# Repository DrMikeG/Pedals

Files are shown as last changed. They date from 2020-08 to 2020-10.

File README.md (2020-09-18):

# Pedals

conversation:

- General
- Bach and piano

- Electric piano (Dad was a vicar - church organ)
- Foot pedals and midi

- Organ pedals.

Fotdella

12 pedals.

On/off
Force / impulse to determine volume (optional)

Plugs into keyboard.

Untransposed note?

- Recording
- Bass

- Roland VR-09B Combo

Pedalboard: PK-9

AC adaptor Via PK cable

MP-113
Width: 54 cm / 21,3"
Depth: 42 cm / 16,5"
Height: 14 cm / 5,5"

https://www.thomann.de/gb/doepfer_mbp25_electronic_with_1_pedal.htm

dimension of one bass pedal: about 530 mm (length) x 380 mm (depth) x 95 mm (height)

480

446 + 1 space

10 white keys
7 black keys
2 gaps

19 key
18 gaps

# Project Update 18th September #

I'm making this because I have a friend who is interested in trying to play it - but not interested enough to pay £500 to try playing it.
And I've really been enjoying this project.

I don't usually do work in progress videos, but this project has been going over a month now, and I felt I had learned enough to warrant a quick recap.

I'm attempting to build - from scratch, a set of 13 midi organ-style pedals.

It will be mostly 3d printed, and I'm using magnets and hall effects sensors.

I'm using the hugely powerful Teensie 4.0 as the midi controller, and that has 14 analog inputs, which greatly simplifies the build.

Power requirements.
I had a KY-024 linear hall effect breakout board in my parts bin so I started designing around that, rather than the raw sensor.
It has useful features, such as a power LED and an onboard comparator so it can return either an analog or digital reading, with a trim pot to adjust the digital sensitivity.
Now I plan on going analog, because I plan on measuring key velocity, but being able to use the build in LEDs for power and signal is really appealing for debugging the build.

The power draw of the board was a concern, because the Teensie is limited to 250ma (which itself is impressive for a microcontroller regulator) - but had literally no idea what the 13 KY-024 dev boards might draw.
Measuring it, I came out with 6.5mA - which sounded much too low for two bright (althought small) LED - but having sought some advice from the PJRC forum, it seems that is resonable, and I can power all 13 boards direct from the teensie.

I aiming to keep the BOM low, so I'm trying to use commodity parts. When you start to multply everything by even just 13 - things start to get expensive.

Designing the keys.

My key design is a simple pivot. I considered levers and gears, but discussing that with the my friend who has experience with organ pedals, they don't tend to have much simpler mechanics than piano keys.

Springs are expensive - and to start with I wanted large compass springs like many organ pedals used. I made a rig to bend coat hanger wire into springs.
That worked surprisingly well, although with a double coil the springs were much two powerful, and with only a single coil they tended to bend plastically not elastically.

So I trawled ebay for cheap springs and found 20 tension springs for £6. So I splashed out.
It turns out that 15mm springs are very small, but strong enough for my purpose.
But it required a major key re-design to make a level long enough for the spring travel.

Making a full size cardboard mock of the keyboard taught me lots of things.

Firsty, the keys are tightly packed. I mean, really tight. The width of keyboard I wanted was just wide enough for the dev boards.
Which is helpful because it means I can design sharp and natural keys with the same mechanism, not having to design neighbouring keys with an offset.

It turns out that although the distance moved

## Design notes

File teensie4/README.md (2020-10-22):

I've just started looking at the teensie 4.0

It has 14 analog pins, but 4 of them are on the rear of the board, not accessed via holes.

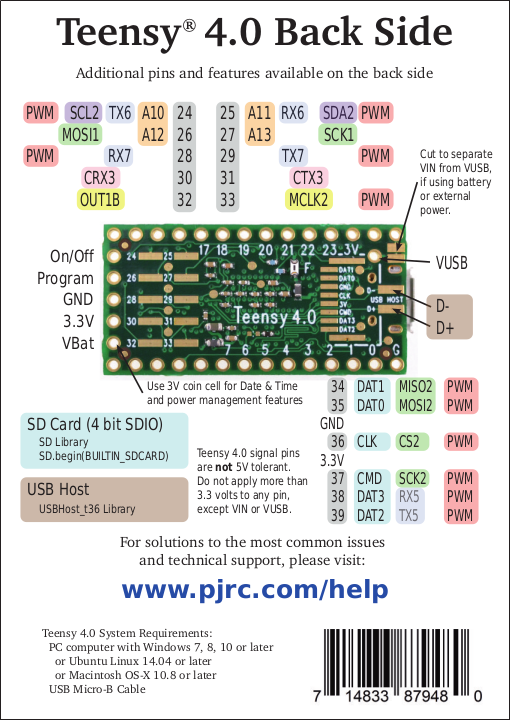
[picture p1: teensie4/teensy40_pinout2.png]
Teensy Rear Side


I'm going to want access to pins 24-27.

There is a discussion of how to do this here:
https://forum.pjrc.com/threads/59817-Teensy-4-0-accesing-24-to-33-pines?highlight=pogo

I have ordered https://www.sparkfun.com/products/13925 this pin header set via ebay.

In the mean time I want to research two components:

KY-024 Hall Effect breakout.

https://arduinomodules.info/ky-024-linear-magnetic-hall-module/

Wired up to the nano using 3v power. Using arduino serial plot. The flat side of the package seems to be where you want to position the magnet for best reading/range.

These seem really easy, so I've ordered a stack of these. Need to think about a 3d holder.

KY-016 RGB Full Colour LED.

https://arduinomodules.info/ky-016-rgb-full-color-led-module/

Teensie Midi

https://www.pjrc.com/teensy/td_libs_MIDI.html

MIDI uses the hardware serial ports to communicate with standard MIDI devices at 31250 baud.
This page documents ordinary serial MIDI which uses round 5-pin DIN connectors.
You can use Serial.print() to observe what your program is doing, while using MIDI, or USB MIDI.

MIDI input requires an optically isolated input. Output requires only 2 resistors. This schematic is recommended for Teensy 4.x & 3.x & LC:

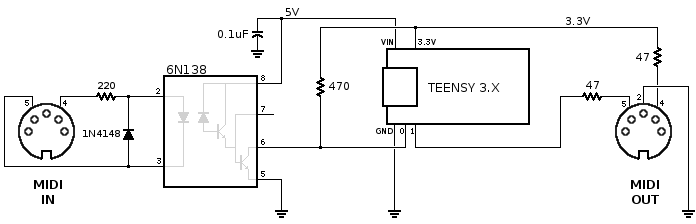
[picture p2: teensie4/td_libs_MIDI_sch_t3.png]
Midi Circuit


When connecting the signals on the 5 pin DIN connectors, be sure to connect to the correct pins.

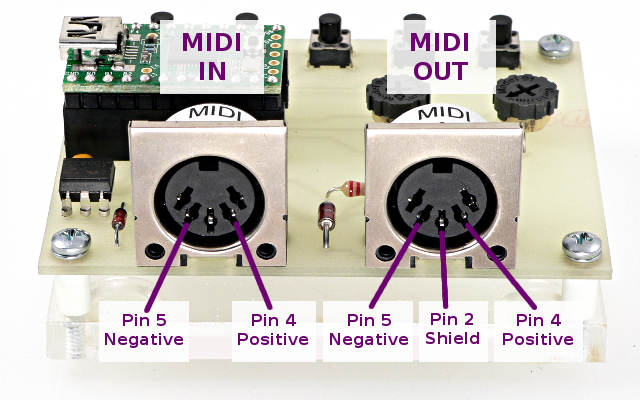
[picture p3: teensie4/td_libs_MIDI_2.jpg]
Midi Wiring


So, let's see if I understand this:

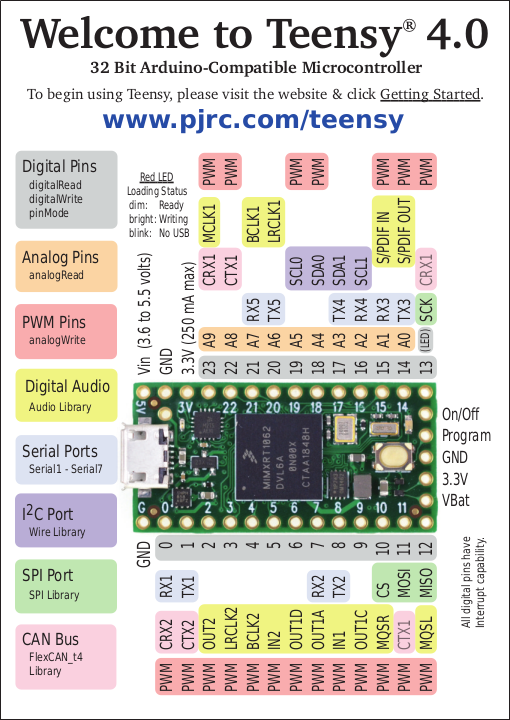
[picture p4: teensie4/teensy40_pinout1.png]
Teensy Front Side


47 ohm resistors

GND wire to pin 2 
Pin 1 is TX1 via 50ohm resistor to send - pin 5 on DIN
3.3V wire via 50ohm resistor to pin 4 (positive)

I've arranged the 3 pin headers in an L-shape
[1][2]
   [3]

[1] = rx/1 din pin 5 orange
[2] = 3.3v din pin 4 green
[3] = gnd  din pin 2 yellow

[orange][green ]
        [yellow]

https://forum.pjrc.com/threads/61941-Exponential-Moving-Average-How-does-it-work

6.5ma = 85ma

Most 3mm LEDs will be rated 20mA maximum, so 30mA is possibly bad for them.  Modern hyperbright LEDs need a lot less than 20mA to be
bright enough for indoor use...  Perhaps your 3mm LEDs are only superbright or ultrabright? (Actually I can't remember which of
these ghastly marketing terms is supposed to be the brightest!).

As LEDs evolved from the first primitive red GaAs LEDs the brightness was improved a 1000 times or more, so there are lots of different
brightnesses available depending on the process used.  The datasheet will normally say what the luminous intensity, beam angle and
luminous flux are for a given forward current.  Just beam angle can have massive effect on luminous intensity.

These days properly bright LEDs use heterojunction/quantum well design similar to semiconductor lasers, and are getting pretty close to
100% quantum efficiency.

1--5mA is normally plenty for a modern indicator LED.  The smaller the LED the less current you need for it to hurt your eyes!

## 14th Sept 2020 ##

I've printed KeyMechRig05.stl and KeyMech02.par
Changes required.
Spring needs to mount parallel betwee rear arm and rear fixing. Needs more stretch at rest 2-3mm
Could change mounting position to print without support if it only pulled on one side of the rear post.

Board mount for sensor is higher than before. Lower by ~2 mm
Board still tends to twist. Add bar at rear and tabs at front,

Cannot tap screws into central screw holes. Not enough clearance.
Front and rear screw holes are a bit close to the front surfaces.

How to wire FC16P

## Start again ##

I wired up all the analog pins incorrectly - I mirrored the pin placement and wired them up to the digital pins on the wrong edge of the teensy.

Doh.

Thankfull I was able to remove the teensie from the protoboard and start again.

My on/off switches arrived today. They have an internal resistor for the LED.

They draw about 1ma at 3.3V.
If I connect black to gnd and brown to 3.3 then the LED lights up when the teensy is on.
If I wire yellow to gnd and orange to on/off - then a long hold turns off the teensie (this turns off 3.3V but not 5V) so the LED goes off. A short press turns it back on.
Can I reduce the number of wires to 3? I've asked the forum because I am not sure.

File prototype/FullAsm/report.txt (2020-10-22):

Report Name: C:\Users\gibbens\Documents\Arduino\Pedals\prototype\FullAsm\report.txt
Report Time: 24/09/2020 18:41:09
Report Options:
    Part Names

Select Set #1:
    MockKeyNatural.par:2

Select Set #2:
    LeftRailHolder.par:1

Interferences:
    1 of 1
    MockKeyNatural.par:2
    LeftRailHolder.par:1

    1 Interferences Detected

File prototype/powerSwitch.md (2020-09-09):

This strain relief bar has 2.75mm holes (which are threaded by M2.5 screws.)
The holes are 40.8mm apart to match short side of perf board
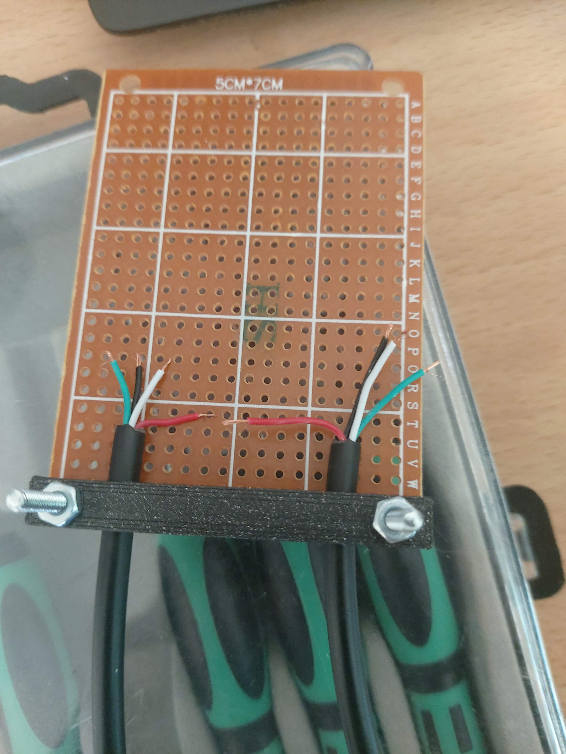
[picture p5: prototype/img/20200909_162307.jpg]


What about the micro usb wire colours?

Red     Ground

Black   D+

White   VCC

Green   D-

Not trusting the breakout board entirely,
I just put a battery pack on the socket end and did indeed get +5V from White to Red!

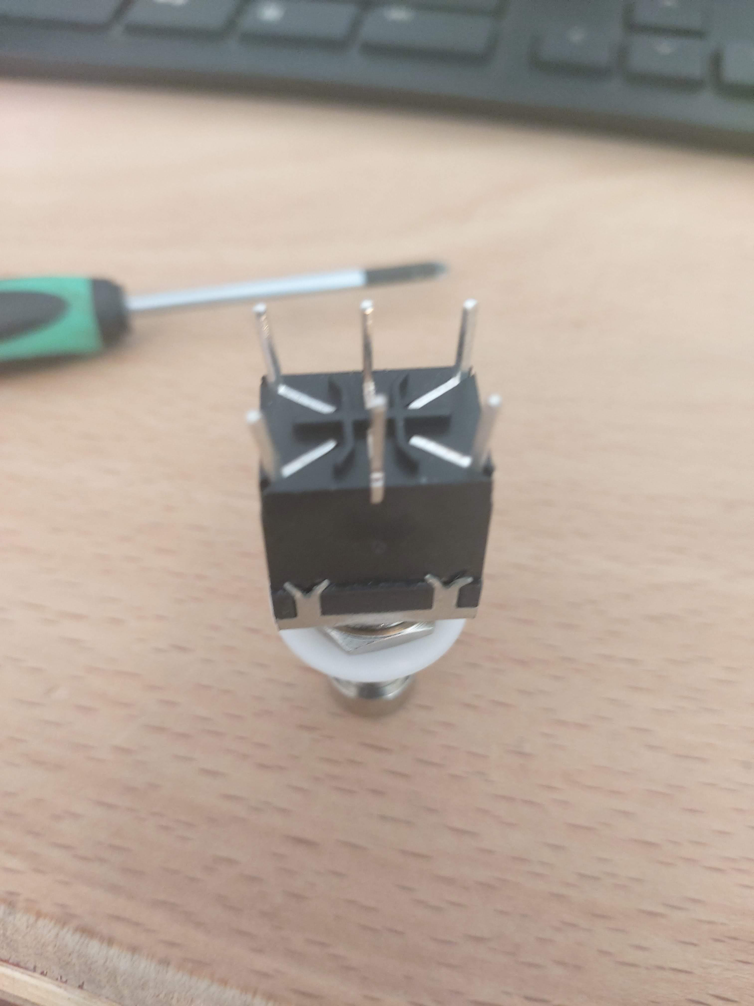
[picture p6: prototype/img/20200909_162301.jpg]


The switch is two 3 terminal switches.
Along each long side are three legs, A,B,C
B is the common terminal, switching between AB and BC.

I plan to put ground on one side and 5V on the other.

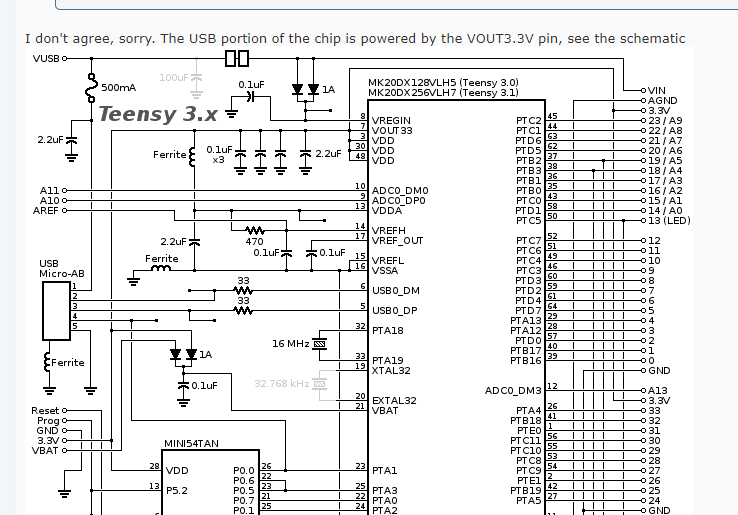
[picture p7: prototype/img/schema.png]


My question was can I just run 5v into the teensie via the microUSB connector and tap off the Vin pin to power all my 13 hall effects boards (26 LEDS!)

Looks like the answer is no, as I'm guessing the wavy line between the micro usb pins and VUSBin is some sort of fuse.

So, I will need to tap off the switch board another 5V source.

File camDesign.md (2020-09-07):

https://nolte-nc-kurventechnik.homepage.t-online.de/en/cam-design.html

Cam
Follower

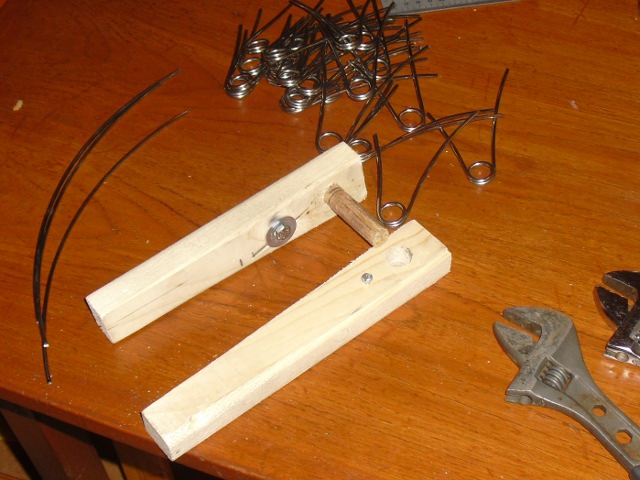
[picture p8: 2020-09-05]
prototype/img/springtools.jpg

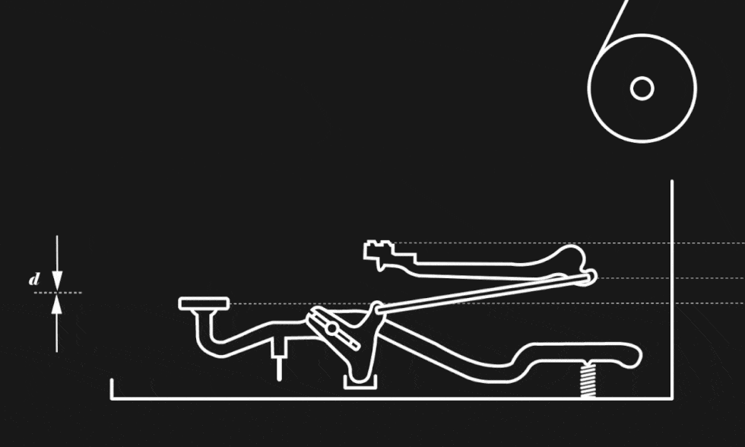
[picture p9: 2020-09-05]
prototype/img/gallery-1452611667-the-travel-typewriter04.gif

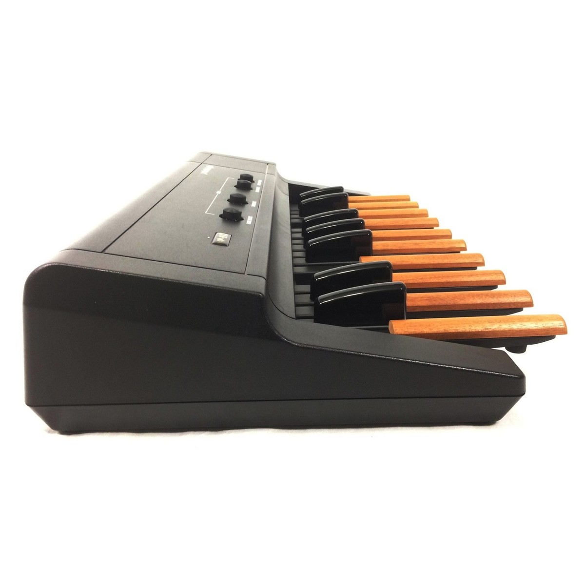
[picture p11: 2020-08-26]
readme_img/stud_03.jpg

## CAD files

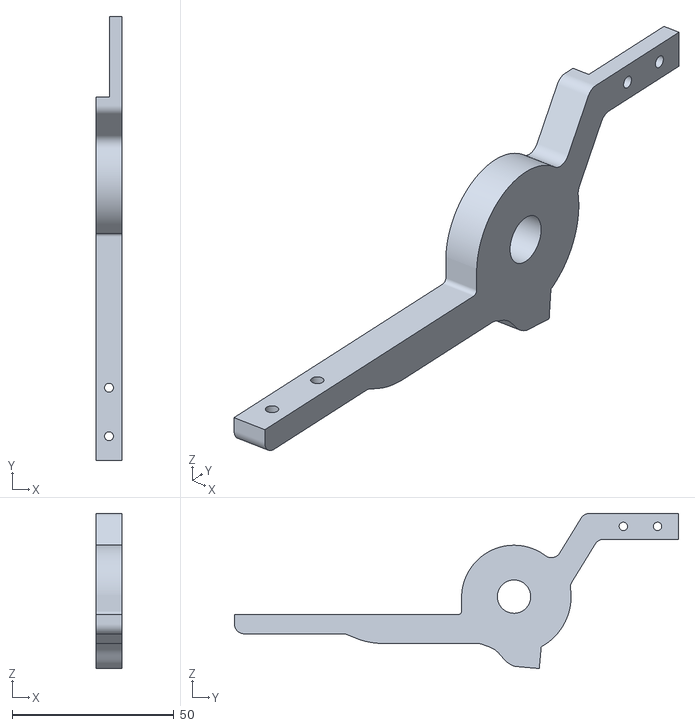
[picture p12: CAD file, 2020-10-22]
prototype/KeyMech05Main.stl
8.00 x 137.3 x 48.0

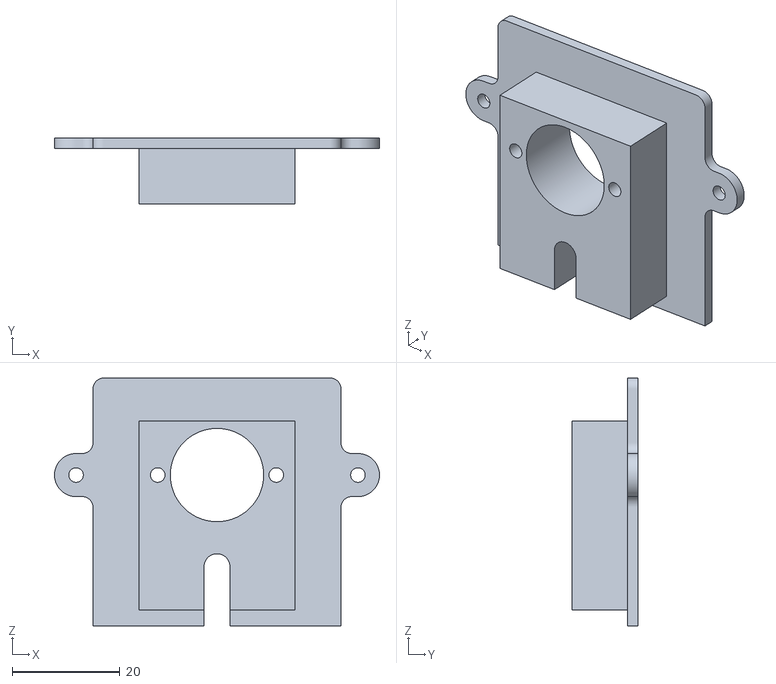
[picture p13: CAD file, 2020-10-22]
prototype/DinSupportRearPlateMain.stl
60.3 x 12.3 x 46.0

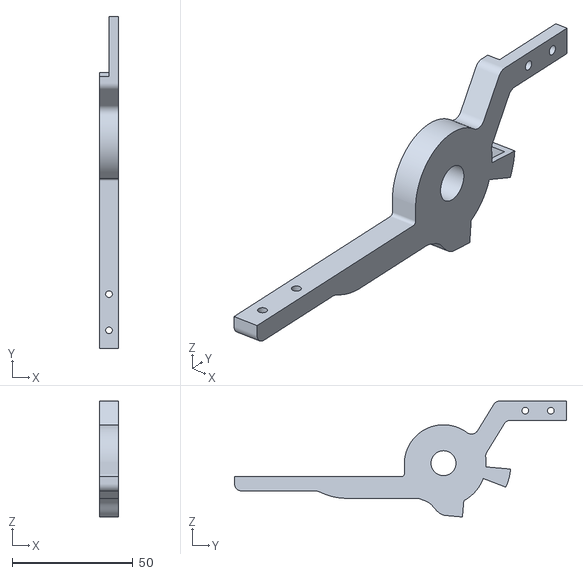
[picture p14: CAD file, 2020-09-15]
prototype/KeyMech04Main_NoBearing.stl
8.00 x 137.3 x 48.0

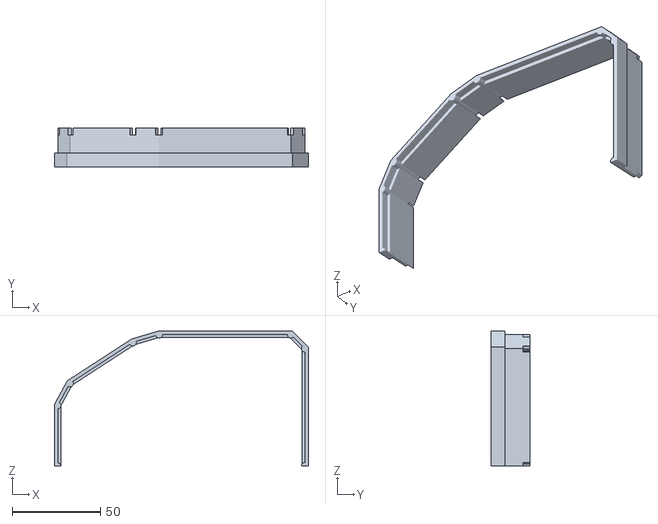
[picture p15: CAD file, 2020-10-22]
prototype/clam/clam01.stl
144.0 x 22.0 x 76.5

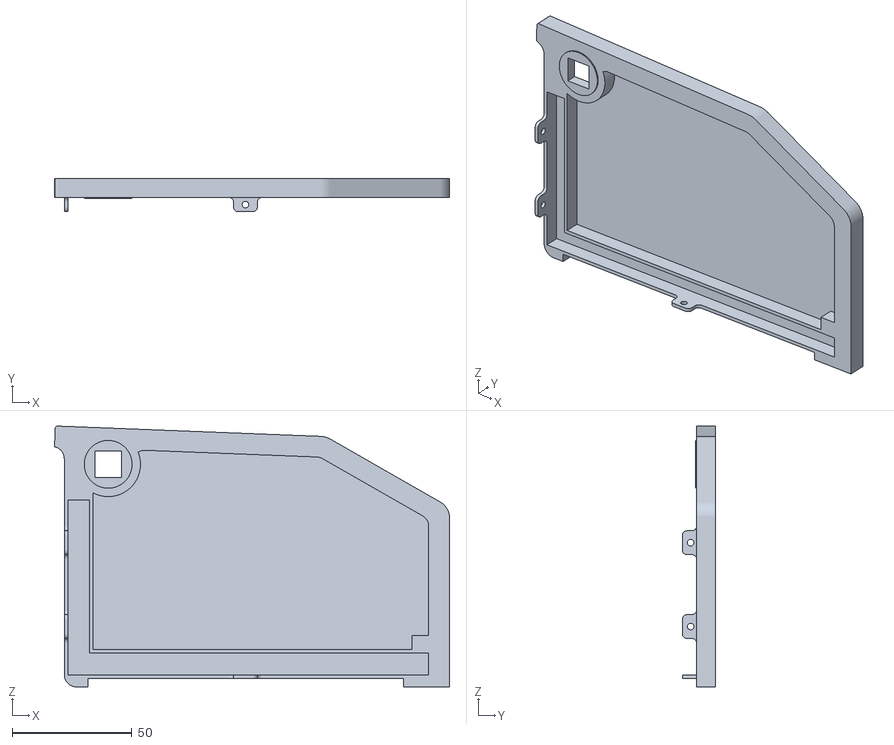
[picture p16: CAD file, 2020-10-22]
prototype/HingeEndDesign02Mirror.stl
165.3 x 14.0 x 109.1

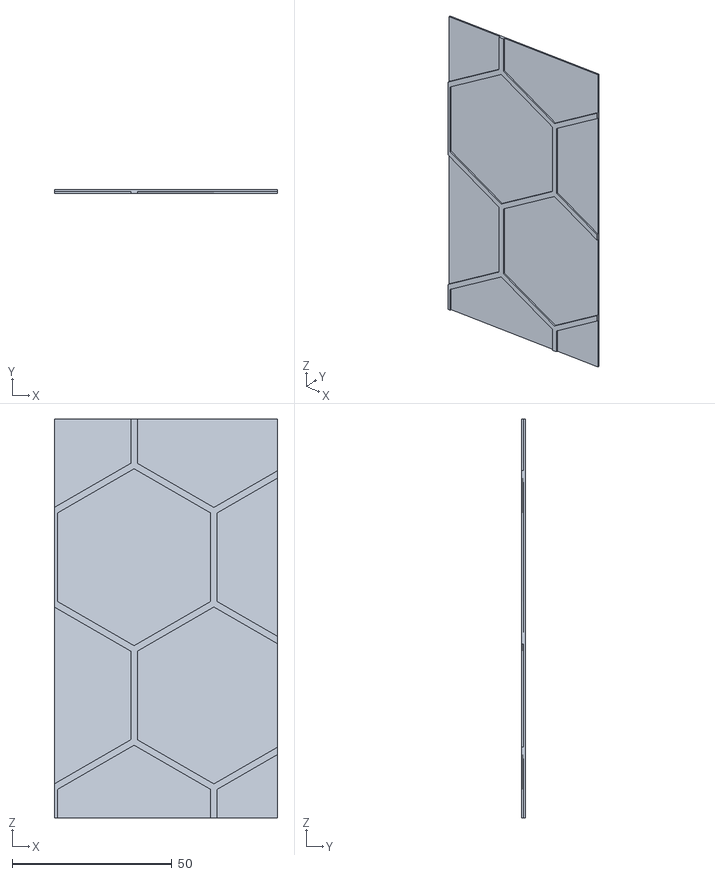
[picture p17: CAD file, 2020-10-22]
prototype/clam/clam02.stl
70.0 x 1.20 x 125.0

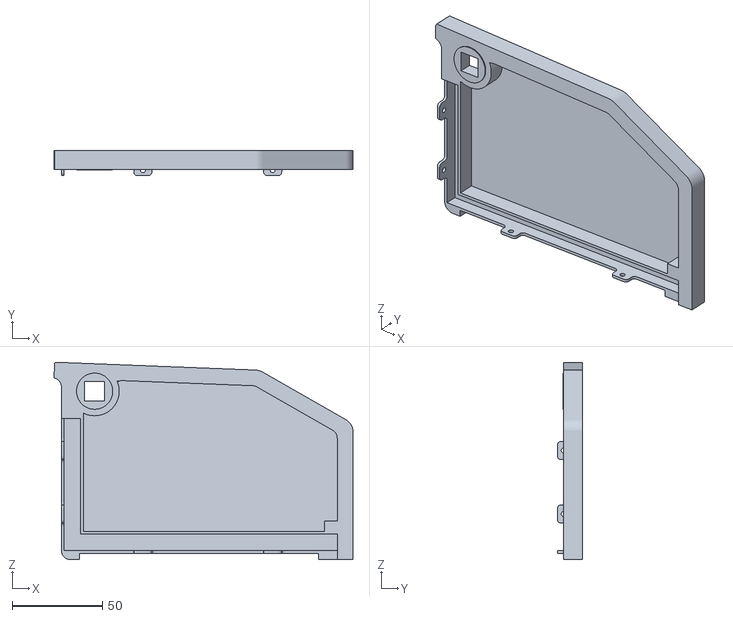
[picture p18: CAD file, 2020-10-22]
prototype/EndDesign02Mirror.stl
165.3 x 14.0 x 109.1

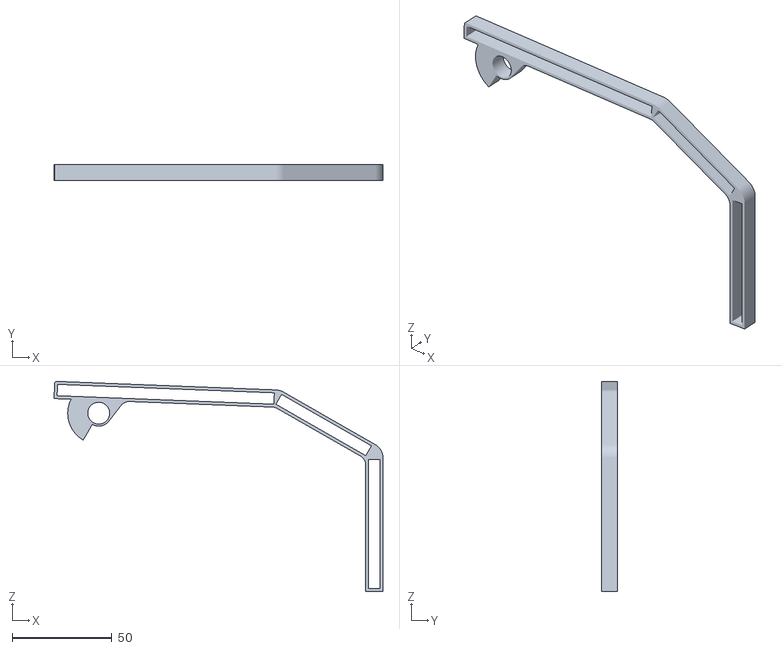
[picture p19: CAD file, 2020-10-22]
prototype/HingeEndDesign01.stl
165.3 x 8.00 x 105.6

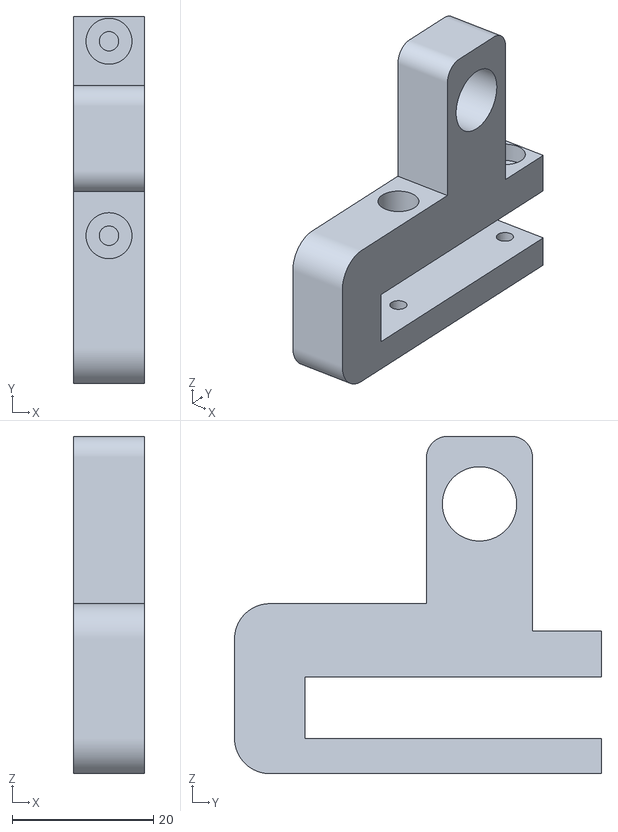
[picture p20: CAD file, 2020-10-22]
prototype/MidRailHolder.stl
10.0 x 51.9 x 47.7

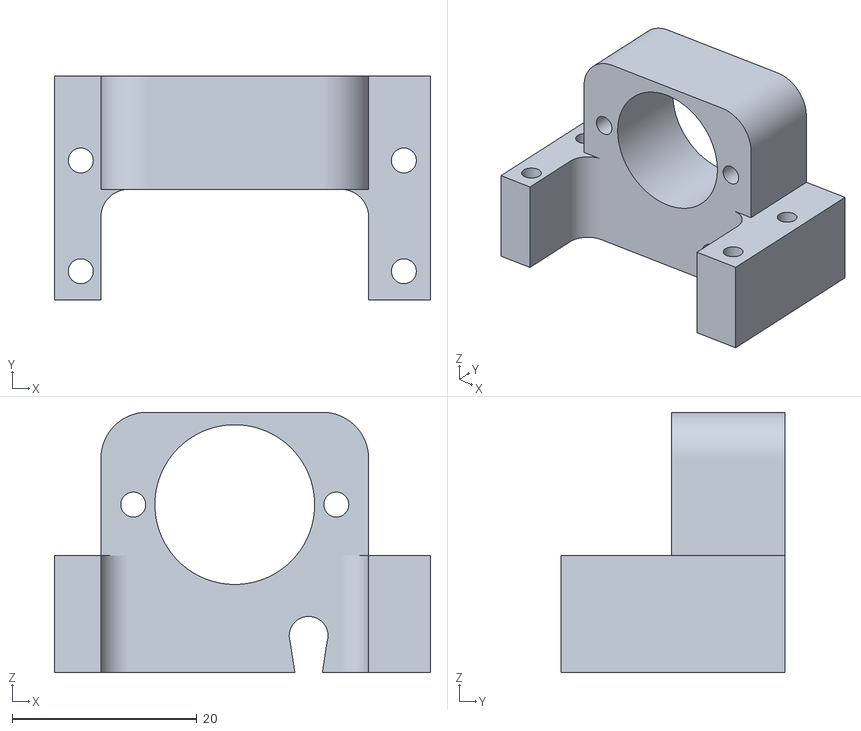
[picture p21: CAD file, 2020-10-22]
prototype/DinSupportAndOnOff.stl
40.7 x 24.3 x 28.2

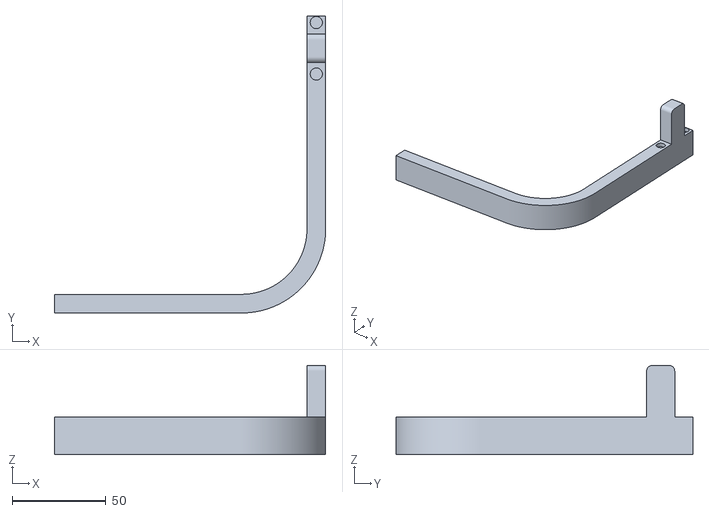
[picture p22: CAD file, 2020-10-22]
prototype/RightRailHolder.stl
145.0 x 158.7 x 47.7

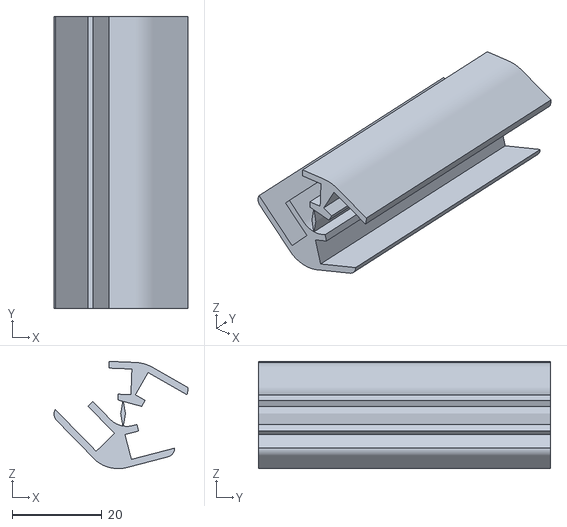
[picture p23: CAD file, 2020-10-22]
prototype/MushroomRailTop01.stl
29.8 x 65.0 x 23.8

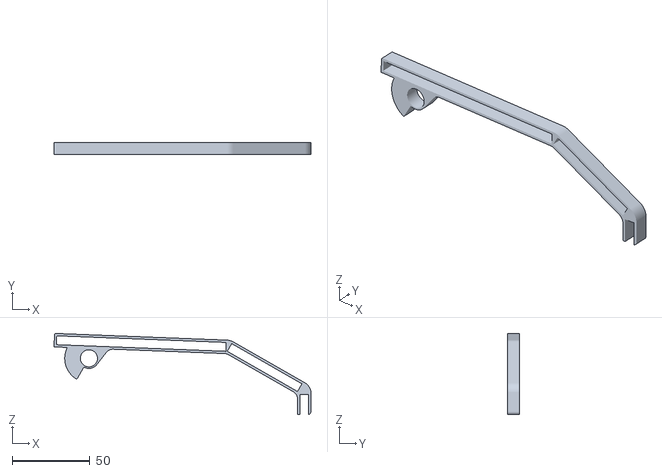
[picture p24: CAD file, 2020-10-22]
prototype/HingeMidDesign01.stl
165.3 x 8.00 x 52.1

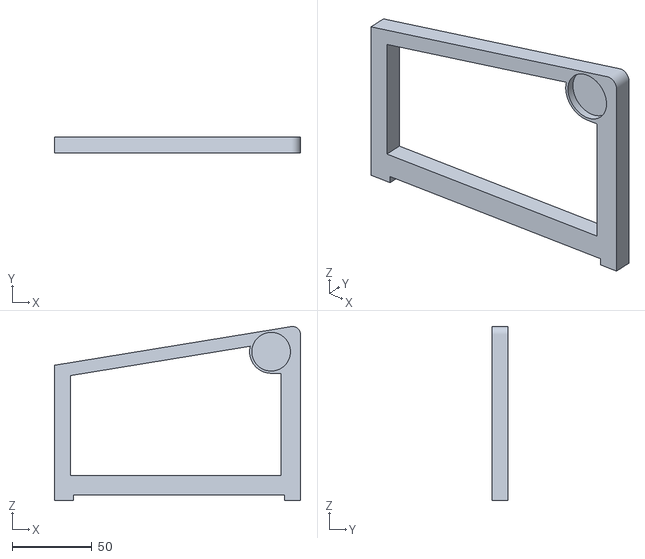
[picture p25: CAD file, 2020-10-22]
prototype/EndDesign01.stl
154.0 x 10.0 x 108.9

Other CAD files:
prototype/KeyMech03Main_NoBearing.stl
prototype/KeyMech03Main_NoBearing2.stl
prototype/EndDesign02.stl
prototype/LeftRailHolder.stl
prototype/BottomPlate01.stl
prototype/BottomPlate02Left.stl
prototype/BottomPlate02Right.stl
prototype/DinSupportRearPlateRelief.stl
prototype/HingeEndDesign02.stl
prototype/KeyMech03RearArm.stl
prototype/KeyMech05RearArm.stl
prototype/KeyMechRig06.stl
prototype/KeyMechRig07.stl
prototype/KeyMechRig08.stl
prototype/MidRailUnmeasured.stl
prototype/Part1.stl
prototype/SingleSpacer1.stl
prototype/TeensieHolder.stl
prototype/older_revisions/KeyMech03Main_NoBearing.stl
prototype/older_revisions/KeyMech03Main_NoBearing2.stl
prototype/older_revisions/KeyMech03RearArm.stl
prototype/older_revisions/KeyMechRig06.stl
prototype/older_revisions/KeyMechRig07.stl
prototype/older_revisions/OnOffMockSupport.stl

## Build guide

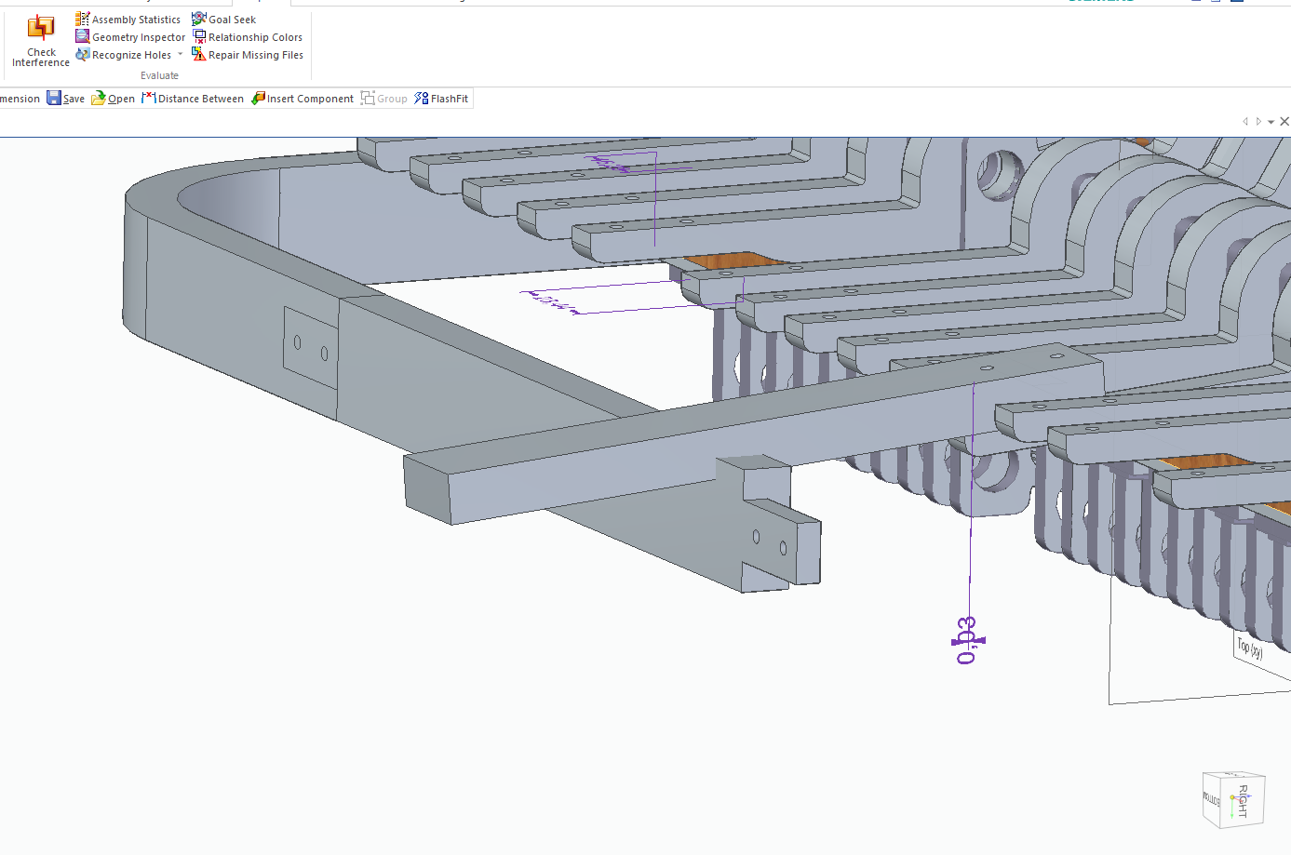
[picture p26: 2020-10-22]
teensie4/AssemblyView.png

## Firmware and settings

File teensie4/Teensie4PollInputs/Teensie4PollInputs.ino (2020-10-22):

#include <MIDI.h>

MIDI_CREATE_INSTANCE(HardwareSerial, Serial1, MIDI);
const int channel = 1;

// Skip A11 because I only need 13 and I burnt the pad off Pin 11...
int pinsToPoll[13] = {A0, A1, A2, A3, A4, A5, A6, A7, A8, A9, A13, A12, A10};
constexpr int pinToPollMax = 13;

int led = 13 ; // LED on arduino
int analogVal; // analog readings

// Triggering variables & consts
int lowWaterMark[13] = {700,700,700,700,700, 700,700,700,700,700, 700,700,700};
int highWaterMark[13] = {0,0,0,0,0, 0,0,0,0,0, 0,0,0};
int triggerWaterMark[13] = {0,0,0,0,0, 0,0,0,0,0, 0,0,0};
bool triggerCalibrated[13] = {false,false,false,false,false, false,false,false,false,false, false,false,false};
constexpr int triggerCalibrationThreshold = 40;

// Average variables & consts
int_fast16_t headings[13] = {0,0,0,0,0, 0,0,0,0,0, 0,0,0};
constexpr int_fast16_t fractional_bits = 1;

// Note variables
int keyVelocity[13] = {0,0,0,0,0, 0,0,0,0,0, 0,0,0} ;
int keyAssignment[13] = {36,37,38,39,40, 41,42,43,44,45, 46,47,48} ;

int_fast16_t average_heading(int i, int_fast16_t sample)
{
    int_fast16_t average;
    headings[i] += sample;
    average = (headings[i] - (headings[i] < 0) + (1 << (fractional_bits - 1))) >> fractional_bits;
    headings[i] -= average;
    return average;
}

void setup() {
  
  pinMode (led, OUTPUT); 

  for (int i=0; i < pinToPollMax; i++)
  {
    pinMode(pinsToPoll[i], INPUT);   
  }
  
  Serial.begin(9600);
  MIDI.begin();
}

constexpr int waitBeforeMakingNoise = 50*pinToPollMax;
int nWaited = 0;

void loop() {

   // Read the analog interface
  for (int i=0; i < pinToPollMax; i++)
  {
    
    analogVal = analogRead(pinsToPoll[i]);
    
      if (analogVal < lowWaterMark[i])
      {
        lowWaterMark[i] = analogVal;
      }
      
      if (analogVal > highWaterMark[i])
      {
        highWaterMark[i] = analogVal;
      }
      

    int differenceBetweenHighAndLowWaterMark = (highWaterMark[i] - lowWaterMark[i]);
    if (differenceBetweenHighAndLowWaterMark > triggerCalibrationThreshold)
    {
      triggerCalibrated[i] = true;
    }
    triggerWaterMark[i] = lowWaterMark[i] + (0.2 * differenceBetweenHighAndLowWaterMark);

    bool displayOn = true;//(i == 12);
    
    if (displayOn)
    {

      int_fast16_t avg = average_heading(i,analogVal);

      if (displayOn)
      {
        Serial.print(avg); // print analog value
        Serial.print(",");              //seperator
        Serial.print(analogVal); // print analog value
       //Serial.print(headings[i]); // print analog value
        Serial.print(",");              //seperator
        if (false)
        {
          Serial.print(lowWaterMark[i]); // print analog value
          Serial.print(",");              //seperator
          Serial.print(highWaterMark[i]); // print analog value
          Serial.print(",");              //seperator
          Serial.print(triggerWaterMark[i]); // print analog value
          Serial.print(",");              //seperator
        }
      }


      // Don't make a noise for the first 
      if (nWaited < waitBeforeMakingNoise)
      {
        nWaited++;
        continue;
      }
      
      if ( avg < triggerWaterMark[i] && triggerCalibrated[i])
      {
        if ( keyVelocity[i] == 0 )
        {
          keyVelocity[i] = 120;
          MIDI.sendNoteOn(keyAssignment[i], keyVelocity[i], channel);
          digitalWrite (led, HIGH);
        }
      } else {
        if ( keyVelocity[i] > 0 )
        {
          keyVelocity[i] = 0;
          MIDI.sendNoteOff(keyAssignment[i], keyVelocity[i], channel);
          digitalWrite (led, LOW);
        }
      }
              
    }
   
  }// end for for each pin
  Serial.print('\n');        
  delay(20);
}

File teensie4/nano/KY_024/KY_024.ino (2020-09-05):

int led = 13 ; // LED on arduino
int digitalPin = 3; // linear Hall magnetic sensor digital interface
int analogPin = A13; // linear Hall magnetic sensor analog interface
int digitalVal ; // digital readings
int analogVal; // analog readings

void setup ()
{
  pinMode (led, OUTPUT); 
  pinMode (digitalPin, INPUT); 
  pinMode(analogPin, INPUT); 
  Serial.begin(9600);
}

void loop ()
{
  // Read the digital interface
  digitalVal = digitalRead(digitalPin) ; 
  if (digitalVal == HIGH) // When magnetic field is present, Arduino LED is on
  {
    digitalWrite (led, HIGH);
  }
  else
  {
    digitalWrite (led, LOW);
  }
  
  // Read the analog interface
  analogVal = analogRead(analogPin);
  Serial.println(analogVal); // print analog value

  delay(100);
}

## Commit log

2020-08-19 First efforts reading hall effect sensor ky-024 using nano
2020-08-26 KeyMech01.stl print 1 Too tight around bearing. (+0.5mm) Too tight around magnet (+0.075mm)
    [KeyMech01.stl]
2020-09-05 Changed Pin to test read side connections of teensie
2020-09-05 Test prints of key rig
    [KeyMechRig03.stl, KeyMechRig04.stl, KeyMechStand01.stl]
2020-09-05 Din support has 2.7mm holes for the 20mm m2.5 machine screws I have most of. When printed these are tight but can be tapped with some force.
    [DinSupport01.stl]
2020-09-06 Velocity output with moving low-watermark
2020-09-07 Designs for front bar parts.
    [FrontBarAsm.cfg, FrontMidBar.stl, FrontRightBar_01.stl]
2020-09-09 Adding power footswitch design
    [StrainReliefBar.stl]
2020-09-09 Switch board assembly
2020-09-13 Key Mech 2 needs splitting into 3 printable bodies.
    [13KeyboardDimensionsBarVariantRearCase.stl]
2020-09-13 Printer Key 2parts a and b. Almost too flexible, too low, does not clear ky board.
    [KeyMech02_a.stl, KeyMech02b.stl]
2020-09-13 Key Mech Rig 5 ready for test print (bed supports). Key Mech 03 Read Arm and Main ready for test print.
    [5Keys.cfg, KeyMech02Main.stl, KeyMech02RearArm.stl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]
2020-09-15 Ready to print key rig 6
    [13KeyboardDimensionsBarVariantRearCase.stl, DinSupport01.stl, FrontMidBar.stl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]
2020-09-15 Key mech 04 main bearing test print (enlarged center hole from 9.8 to 10.3)
    [KeyMech03Main_NoBearing.stl, KeyMech03RearArm.stl, KeyMech04Main_NoBearing.stl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]
2020-09-15 KeyMechRig06 unchanged except for addition of 0.3mm sacrificially bridge at top of supported counterbored hole.
2020-09-16 Worked on rig 7 - savingbefore renaming from 72 (typo)
    [KeyMechRig07.x_t, KeyMechRig072.x_t, SingleKeyAsmUsingRig7.cfg]
2020-09-17 First print of key mech rig 7 (vertical ky board) and key mech 5 (moved magnet holder)
    [KeyMech05Main.stl, KeyMech05RearArm.stl, KeyMechRig07.stl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]
2020-09-18 Key rig 8 tested
    [KeyMechRig08.stl]
2020-09-20 First revision of bottom plate
2020-09-20 Hogged out a load of material to reduce print time
2020-09-20 Revised front bar to account for baseboard. Slightly sketchy design - not sure it will print.
    [BottomPlate01.stl, LeftRailHolder.stl, LeftRailHolder.x_t]
2020-09-21 Reduced tollerances of holes on key and key mech to support higher printer res. Not yet tested.
    [KeyMech03Main_NoBearing.stl, KeyMech03Main_NoBearing2.stl, KeyMech03RearArm.stl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]
2020-09-21 Mirrored rail.
    [MidRailHolder.stl, RightRailHolder.stl]
2020-09-23 Drafted out some new peices. About to lower front bar to avoid clash identified in fullassembly.
    [FullAssembly.cfg, KeyMechRig08.stl, TeensieHolder.stl]
2020-09-24 Designed bottom plate 2 left and right (not printed)
    [BottomPlate02Left.stl, BottomPlate02Right.stl, FullAssembly.cfg]
2020-09-24 Rail measuring and correcting to make fit print bed
    [FullAssembly.cfg, LeftRailHolder.stl, MidRailUnmeasured.stl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]
2020-09-27 Removed an extra pedal from full assembly - which explains why my base board was the wrong size.
    [FullAssembly.cfg, MidRailUnmeasured.stl, Part1.stl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]
2020-09-29 Printed final pedals today. Saving before considering wider baseboard
    [DinSupportAndOnOff.stl, FullAssembly.cfg, OnOffMockSupport.stl]
2020-10-08 About to revise teensy holder.
    [FullAssembly.cfg, SingleSpacer1.stl, clam01.stl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]
2020-10-11 lid strut design
    [EndDesign01.stl, FullAssembly.cfg, HingeEndDesign01.stl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]
2020-10-15 New designed for hinges. Changed EndDesign2 to make it wider to fill gaps to lid.
    [DinSupportRearPlateMain.stl, DinSupportRearPlateRelief.stl, EndDesign02.stl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]
2020-10-15 Improved end design. Added mid cover struts Added first attempt at gap cover
    [EndDesign02.stl, HingeMidDesign01.stl, MushroomRailTop01.stl]
2020-10-22 Removed volocity code, upped volume, put wait to allow calibration before making any noise.
    [Teensie4PollInputs.ino]
